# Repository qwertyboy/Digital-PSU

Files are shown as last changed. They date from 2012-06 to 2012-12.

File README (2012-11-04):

Digital PSU

This originally started life as the revision B EEVBlog power supply project, but I have made several changes to my version of the design. The first revision of ym design was pretty much a carbon copy of the EEVBlog design, but removed the USB jack and the micro current section. The board was designed with all through-hole components, except for the components that only come in SMD packages, and as a result, was larger and more expensive to produce. The new version, however, only uses through-hole versions of the DAC, ADC, op-amps, the LT3080, and a couple filter capacitors. Instead of using an atmega328 now, it uses an Xmega A4, both for speed and for I/O count. Also changed are the elimination of the push-buttons and MCP23008 I/O expanders.

Key Features:
	-Xmega A4 simplifies design by eliminating need for I/O expansion
	-LT3080 as main output regulator
	-MCP4922 digital-to-analog converter
	-MCP3204 analog-to-digital converter
	-MAX4080F for current sensing
	-Easily readible OLED display
	-Intuitive menu system for set-up and calibration

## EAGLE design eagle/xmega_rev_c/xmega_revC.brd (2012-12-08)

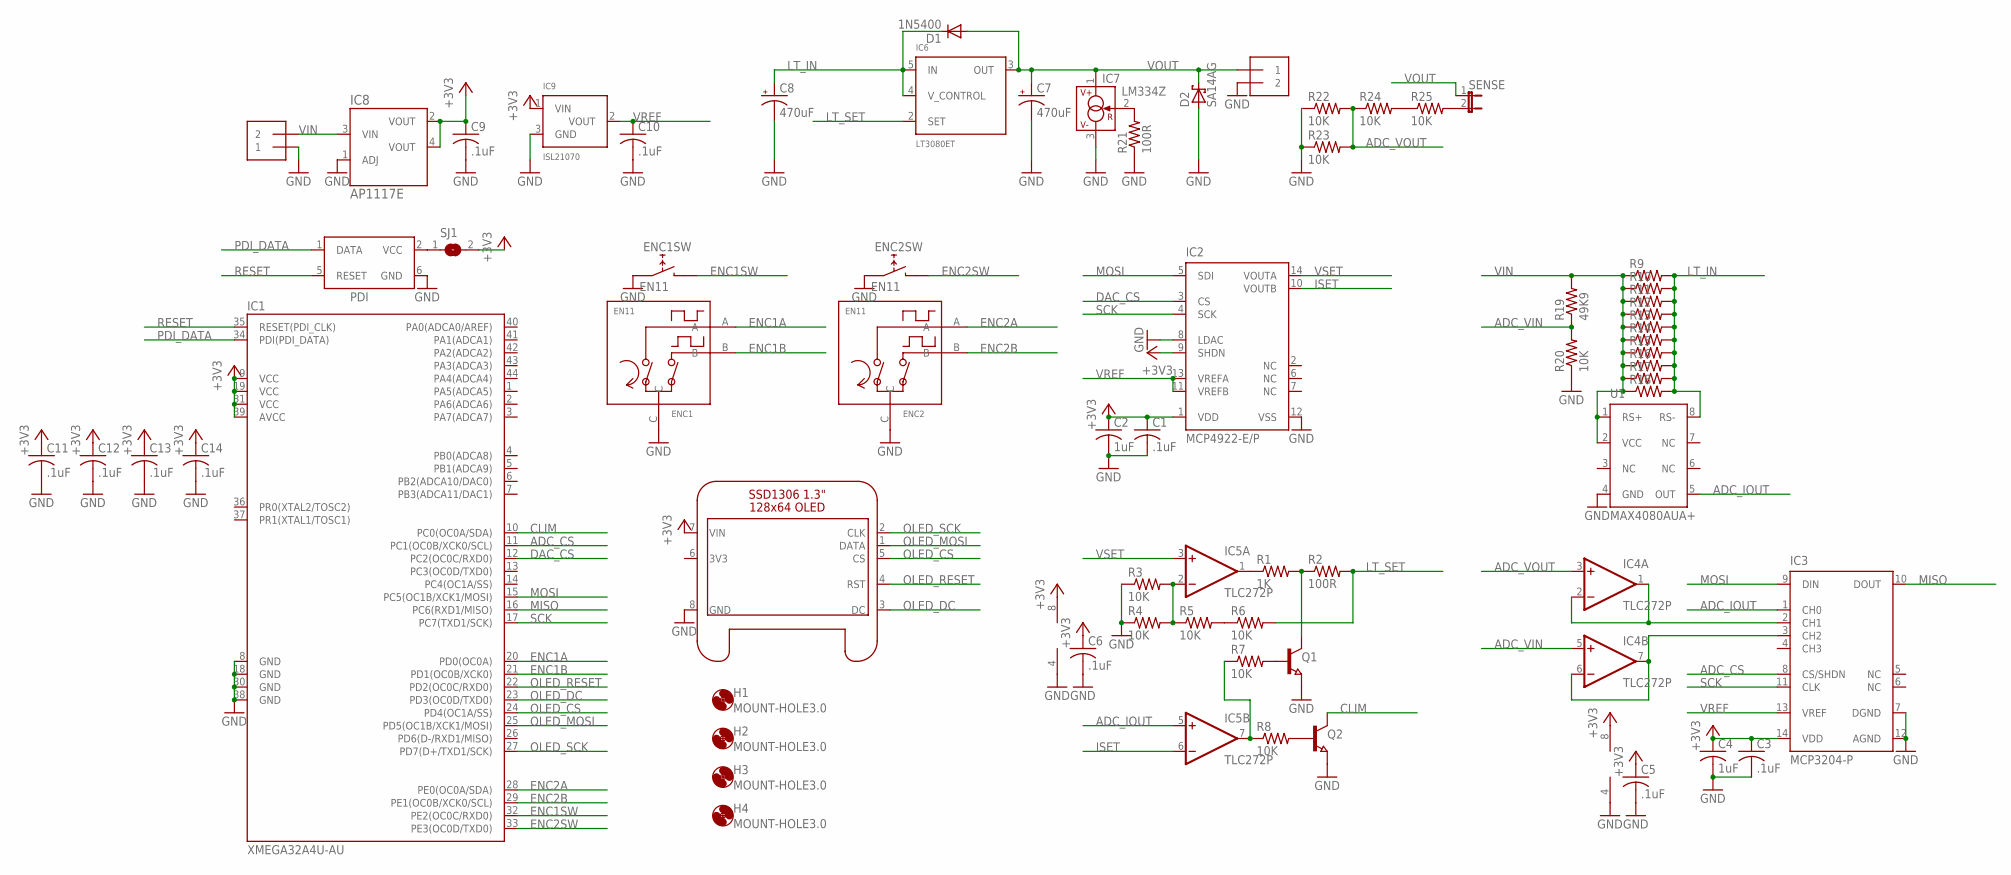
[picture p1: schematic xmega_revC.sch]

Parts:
C1, C3, C5, C6, C9, C10: .1uF; C050-024X044
C2, C4: 1uF; C050-024X044
C7, C8: 470uF; E5-10,5
C11, C12, C13, C14: .1uF; C0805K
D1: 1N5400; DO201-15
D2: SA14AG; DO41-7
ENC1, ENC2: EN11; EN11-VS*
H1, H2, H3, H4: MOUNT-HOLE3.0; 3,0
IC1: XMEGA32A4U-AU; TQFP44
IC2: MCP4922-E/P; DIL14
IC3: MCP3204-P; DIL14
IC4, IC5: TLC272P; DIL08
IC6: LT3080ET; TO220-51
IC7: LM334Z; TO92
IC8: AP1117E; SOT223-3
IC9: ISL21070; SOT-23
OLED1: 128X64_OLED
OUT: 1X2-3.5MM
PDI: XMEGAPDI; AVRISP
Q1, Q2: NPN-TRANSISTOR_SOT23; SOT23
R1: 1K; R0805
R2, R21: 100R; R0805
R3, R4, R5, R6, R7, R8, R20, R22, R23, R24, R25: 10K; R0805
R9, R10, R11, R12, R13, R14, R15, R16, R17, R18: R-US_0207/10; 0207/10
R19: 49K9; R0805
SENSE: JP1E; JP1
SJ1: SJ
U1: MAX4080AUA+; SO08
VIN: 1X2-3.5MM

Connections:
3V3: OLED1.6 (3V3)
+3V3: C1.1, C2.1, C3.1, C4.1, C5.1, C6.1, C9.1, C11.1, C12.1, C13.1, C14.1, IC1.9 (VCC), IC1.19 (VCC), IC1.31 (VCC), IC1.39 (AVCC), IC2.1 (VDD), IC2.9 (SHDN), IC3.14 (VDD), IC4.8 (V+), IC5.8 (V+), IC8.2 (VOUT), IC8.4 (VOUT), IC9.1 (VIN), OLED1.7 (VIN), SJ1.2
ADC_CS: IC1.11 (PC1(OC0B/XCK0/SCL)), IC3.8 (CS/SHDN)
ADC_IOUT: IC3.1 (CH0), IC5.5 (+IN), U1.5 (OUT)
ADC_VIN: IC4.5 (+IN), R19.1, R20.2
ADC_VOUT: IC4.3 (+IN), R22.2, R23.2, R24.1
CLIM: IC1.10 (PC0(OC0A/SDA)), Q2.3 (C)
DAC_CS: IC1.12 (PC2(OC0C/RXD0)), IC2.3 (CS)
ENC1A: ENC1.A, IC1.20 (PD0(OC0A))
ENC1B: ENC1.B, IC1.21 (PD1(OC0B/XCK0))
ENC1SW: ENC1.E, IC1.32 (PE2(OC0C/RXD0))
ENC2A: ENC2.A, IC1.28 (PE0(OC0A/SDA))
ENC2B: ENC2.B, IC1.29 (PE1(OC0B/XCK0/SCL))
ENC2SW: ENC2.E, IC1.33 (PE3(OC0D/TXD0))
GND: C1.2, C2.2, C3.2, C4.2, C5.2, C6.2, C7.-, C8.-, C9.2, C10.2, C11.2, C12.2, C13.2, C14.2, D2.A, ENC1.C, ENC1.D, ENC2.C, ENC2.D, IC1.8 (GND), IC1.18 (GND), IC1.30 (GND), IC1.38 (GND), IC2.8 (LDAC), IC2.12 (VSS), IC3.7 (DGND), IC3.12 (AGND), IC4.4 (V-), IC5.4 (V-), IC7.3 (V-), IC8.1 (ADJ), IC9.3 (GND), OLED1.8 (GND), OUT.2, PDI.6 (GND), Q1.2 (E), Q2.2 (E), R3.1, R4.1, R20.1, R21.1, R22.1, R23.1, U1.4 (GND), VIN.1
ISET: IC2.10 (VOUTB), IC5.6 (-IN)
LT_IN: C8.+, D1.C, IC6.4 (V_CONTROL), IC6.5 (IN), R9.2, R10.2, R11.2, R12.2, R13.2, R14.2, R15.2, R16.2, R17.2, R18.2, U1.8 (RS-)
LT_SET: IC6.2 (SET), R2.2, R6.2
MISO: IC1.16 (PC6(RXD1/MISO)), IC3.10 (DOUT)
MOSI: IC1.15 (PC5(OC1B/XCK1/MOSI)), IC2.5 (SDI), IC3.9 (DIN)
unnamed: IC3.2 (CH1), IC4.1 (OUT), IC4.2 (-IN)
unnamed: IC3.3 (CH2), IC4.6 (-IN), IC4.7 (OUT)
unnamed: IC5.1 (OUT), R1.1
unnamed: Q1.3 (C), R1.2, R2.1
unnamed: IC5.2 (-IN), R3.2, R4.2, R5.1
unnamed: R5.2, R6.1
unnamed: Q1.1 (B), R7.2
unnamed: IC5.7 (OUT), R7.1, R8.1
unnamed: Q2.1 (B), R8.2
unnamed: R25.2, SENSE.2
unnamed: PDI.2 (VCC), SJ1.1
unnamed: IC7.2 (R), R21.2
unnamed: R24.2, R25.1
OLED_CS: IC1.24 (PD4(OC1A/SS)), OLED1.5 (CS)
OLED_DC: IC1.23 (PD3(OC0D/TXD0)), OLED1.3 (DC)
OLED_MOSI: IC1.25 (PD5(OC1B/XCK1/MOSI)), OLED1.1 (DATA)
OLED_RESET: IC1.22 (PD2(OC0C/RXD0)), OLED1.4 (RST)
OLED_SCK: IC1.27 (PD7(D+/TXD1/SCK)), OLED1.2 (CLK)
PDI_DATA: IC1.34 (PDI(PDI_DATA)), PDI.1 (DATA)
RESET: IC1.35 (RESET(PDI_CLK)), PDI.5 (RESET)
SCK: IC1.17 (PC7(TXD1/SCK)), IC2.4 (SCK), IC3.11 (CLK)
VIN: IC8.3 (VIN), R9.1, R10.1, R11.1, R12.1, R13.1, R14.1, R15.1, R16.1, R17.1, R18.1, R19.2, U1.1 (RS+), U1.2 (VCC), VIN.2
VOUT: C7.+, D1.A, D2.C, IC6.3 (OUT), IC7.1 (V+), OUT.1, SENSE.1
VREF: C10.1, IC2.11 (VREFB), IC2.13 (VREFA), IC3.13 (VREF), IC9.2 (VOUT)
VSET: IC2.14 (VOUTA), IC5.3 (+IN)

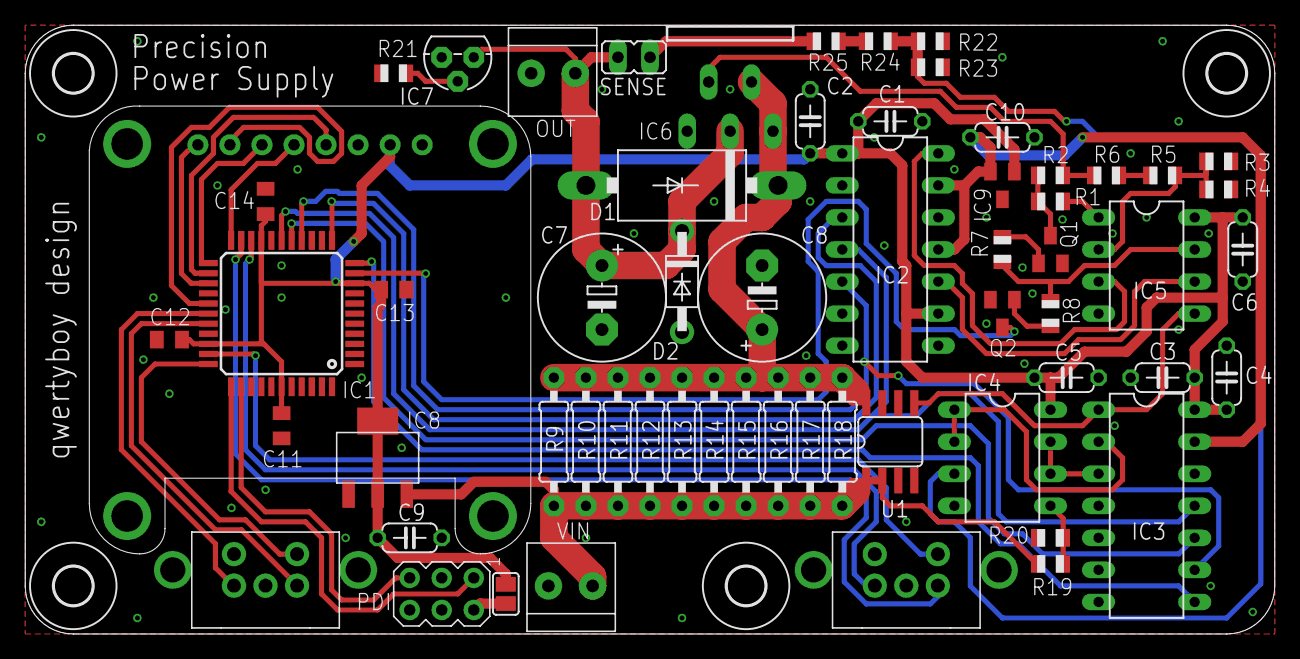
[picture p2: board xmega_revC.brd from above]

Board: 2 copper layers, 99.1 x 48.3 mm, 65 parts (0 on the bottom side), 44 nets.

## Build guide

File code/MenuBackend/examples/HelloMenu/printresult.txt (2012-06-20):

Setting up menu...
Starting navigation (see source for description):
Menu change MenuRoot File
Menu change File New
Menu change New Open
Menu change Open Examples
Menu change Examples ArduinoISP
Menu use ArduinoISP
menuUseEvent found ArduinoISP
Menu change ArduinoISP Examples
Menu change Examples Open
Menu change Open New
Menu change New File
Menu change File Edit
Menu change Edit Sketch
Menu change Sketch Verify
Menu use Verify
Menu change Verify Sketch
Menu change Sketch Edit
Menu change Edit File
Menu change File New
Menu use New
Menu use Verify
menuUseEvent found Verify (V)

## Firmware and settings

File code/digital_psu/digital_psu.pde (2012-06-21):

//Board should be set to "Arduino Pro or Pro Mini (3.3V, 8MHz) w/ ATmega328"
#include <WProgram.h>
#include <Wire.h>
#include "ST7036.h"
#include "LCD_C0220BiZ.h"
#include "MCP23008.h"
#include <MenuBackend.h>

//-----------------------------------------------------------------------------------------------------------------------------------------------------------------//
//Variable nad constant initialization, initialiazation of MCP23008 library, ST7036 librar

//Start 2 instances of MCP23008 library
MCP23008 mcp_internal;  //This one is for controlling various peripherals
MCP23008 mcp_general;  //This one is for general purpose use. The LCD backlight is also on here

//Start instance of I2C LCD library
ST7036 lcd = ST7036(2, 20, 0x78);

//Define some constants
//The first four here are on mcp_internal
#define DAC_CS 1
#define ADC_CS 0
#define RANGE 2  //Range selection for rev.B boards, not used anyway
#define LCD_RESET 3

//These are on mcp_general
#define BACKLIGHT_PIN 7
byte buttons[] = {0, 0, 0, 0};  //Array to store states of onboard buttons
#define MENUBUTTON 0

//Rotary encoder pins
#define ENC1A 2
#define ENC1B 4
#define ENC2A 3
#define ENC2B 7

//These are the counts for the rotary encoders. They are volatile because they will be modified
//in an interrupt and we don't want the compiler to try and optimise these
volatile unsigned int VOLTAGE_POS = 0;
volatile unsigned int CURRENT_POS = 0;

//ADC stuff
int adcVals[] = {0, 0, 0, 0};  //Array to store the different ADC values
//Define some ADC constants
#define IOUT200 0
#define IOUT 1
#define VOUT 2
#define VIN 3
float VOLTAGE_PRINT_DIVISOR = 333.889816;  //This is to output the correct value after voltage
                                           //divider and ADC. Only to be used for VIN

//These are for SPI communication and are located directly on the AVR
#define SPI_DATA A0
#define SPI_CLK A3
#define ADC_DATA A1
#define SPI_CLK_CTRL digitalWrite(SPI_CLK, HIGH); digitalWrite(SPI_CLK, LOW);  //Macro to 'clock' the clock

//-----------------------------------------------------------------------------------------------------------------------------------------------------------------//

//MULTI-CLICK: One Button, Multiple Events

//Timing variables
byte DEBOUNCE = 20;
byte DOUBLE_CLICK_GAP = 250;
byte HOLDTIME = 2000;
byte LONG_HOLDTIME = 5000;

//Other variables
boolean BUTTONVAL = HIGH;
boolean BUTTONLAST = HIGH;
boolean DOUBLE_CLICK_WAITING = false;
boolean DOUBLE_CLICK_UP = false;
boolean SINGLE_OK = true;
long DOWNTIME = -1;
long UPTIME = -1;
boolean IGNOREUP = false;
boolean UP_WAIT = false;
boolean HOLD_EVENT_PAST = false;
boolean LONG_HOLD_EVENT_PAST = false;

//Call to check button
int menuButton()
{
  int event = 0;
  
  //Read button state - first one on mcp_general
  BUTTONVAL = mcp_general.digitalRead(MENUBUTTON);
  
  //Button pressed
  if(BUTTONVAL == LOW && BUTTONLAST == HIGH && (millis() - UPTIME) > DEBOUNCE){
    DOWNTIME = millis();
    IGNOREUP = false;
    UP_WAIT = false;
    SINGLE_OK = true;
    HOLD_EVENT_PAST = false;
    LONG_HOLD_EVENT_PAST = false;
    
    if((millis() - UPTIME) < DOUBLE_CLICK_GAP && DOUBLE_CLICK_UP == false && DOUBLE_CLICK_WAITING == true) DOUBLE_CLICK_UP = true;
    else DOUBLE_CLICK_UP = false;
    DOUBLE_CLICK_WAITING = false;
  }
  
  //Button released
  else if(BUTTONVAL == HIGH && BUTTONLAST == LOW && (millis() - DOWNTIME) > DEBOUNCE){
    if(!IGNOREUP){
      UPTIME = millis();
      if(DOUBLE_CLICK_UP == false) DOUBLE_CLICK_WAITING = true;
      else{
        event = 2;
        DOUBLE_CLICK_UP = false;
        DOUBLE_CLICK_WAITING = false;
        SINGLE_OK = false;
      }
    }
  }
  
  //Normal click event; double click expired
  if(BUTTONVAL == HIGH && (millis() - UPTIME) >= DOUBLE_CLICK_GAP && DOUBLE_CLICK_WAITING == true && DOUBLE_CLICK_UP == false && SINGLE_OK == true){
    event = 1;
    DOUBLE_CLICK_WAITING = false;
  }
  
  //Test for hold
  if(BUTTONVAL == LOW && (millis() - DOWNTIME) >= HOLDTIME){
    //Trigger short hold
    if(!HOLD_EVENT_PAST){
      event = 3;
      UP_WAIT = true;
      IGNORE_UP = true;
      DOUBLE_CLICK_UP = false;
      DOUBLE_CLICK_WAITING = false;
      HOLD_EVENT_PAST = true;
    }
    
    //Trigger long hold
    if((millis() - DOWNTIME) >= LONG_HOLDTIME){
      if(!LONG_HOLD_EVENT_PAST){
        event = 4;
        LONG_HOLD_EVENT_PAST = true;
      }
    }
  }
  BUTTONLAST = BUTTONVAL;
  return event;
}
    
     
//-----------------------------------------------------------------------------------------------------------------------------------------------------------------//

//Menu system! This area contains stuff for setting up and using the menu
/*
root
  Presets      Settings
    1.8V         Calibration
    2.5V           Auto
    3.3V           Manual
    5.0V         LCD
                   Backlight
                   Contrast
*/
//Start instance fo Menu Backend library
MenuBackend menu = MenuBackend(menuUseEvent, menuChangeEvent);

//Preset voltage menu
MenuItem mPresets = MenuItem("Presets");
  MenuItem m1v8 = MenuItem("1.8V");
  MenuItem m2v5 = MenuItem("2.5V");
  MenuItem m3v3 = MenuItem("3.3V");
  MenuItem m5v = MenuItem("5.0V");
  
//Settings menu
MenuItem mSettings = MenuItem("Settings");
  MenuItem mCalibration = MenuItem("Calibration");
    MenuItem mAuto = MenuItem("Auto");
    MenuItem mManual = MenuItem("Manual");
  MenuItem mLCD = MenuItem("LCD");
    MenuItem mBacklight = MenuItem("Backlight");
    MenuItem mContrast = MenuItem("Contrast");
    
void menuSetup()
{
  menu.getRoot().add(mPresets).add(mSettings);           //Add Presets and Settings to root
  mPresets.addRight(m1v8).add(m2v5).add(m3v3).add(m5v);  //Add options under Presets
  mSettings.add(mCalibration).add(mLCD);                 //Add options under Settings
  mCalibration.addRight(mAuto).add(mManual);             //Add options under Calibration
  mLCD.addRight(mBacklight).add(mContrast);              //Add options under LCD
}

void menuUseEvent(MenuUseEvent used)
{
}

//Currently prints what happened to the serial port
void menuChangeEvent(MenuChangeEvent changed)
{
  Serial.print("Menu change ");
  Serial.print(changed.from.getName());
  Serial.print(" ");
  Serial.println(changed.to.getName());
}

//VERY rough way to read buttons, doesn't really work
void menuNav()
{
  if(buttons[0] == 0){
    menu.moveDown();
    delay(10);
  }
  
  if(buttons[1] == 0){
    menu.moveUp();
    delay(10);
  }
  
  if(buttons[2] == 0){
    menu.moveLeft();
    delay(10);
  }
  
  if(buttons[3] == 0){
    menu.moveRight();
    delay(10);
  }
}

//-----------------------------------------------------------------------------------------------------------------------------------------------------------------//

void setup()
{
  Serial.begin(9600);  //Serial for debugging
  
  //Start the library for the two MCP23008's
  mcp_internal.begin(0);
  mcp_general.begin(8);

  //Bring LCD_RESET high to enable LCD
  mcp_internal.pinMode(LCD_RESET, OUTPUT);
  mcp_internal.digitalWrite(LCD_RESET, HIGH);

  //Bring CS lines high to ignore stray data
  mcp_internal.pinMode(DAC_CS, OUTPUT);
  mcp_internal.pinMode(ADC_CS, OUTPUT);
  mcp_internal.digitalWrite(DAC_CS, HIGH);
  mcp_internal.digitalWrite(ADC_CS, HIGH);

  //Set SPI pins as outputs
  pinMode(SPI_DATA, OUTPUT);
  pinMode(SPI_CLK, OUTPUT);
  pinMode(ADC_DATA, INPUT);

  //Set up rotary encoder pins
  pinMode(ENC1A, INPUT);
  pinMode(ENC1B, INPUT);
  pinMode(ENC2A, INPUT);
  pinMode(ENC2B, INPUT);
  digitalWrite(ENC1A, HIGH);
  digitalWrite(ENC1B, HIGH);
  digitalWrite(ENC2A, HIGH);
  digitalWrite(ENC2B, HIGH);
  
  //Set up button inputs on mcp_general
  mcp_general.pinMode(0, INPUT);
  mcp_general.pinMode(1, INPUT);
  mcp_general.pinMode(2, INPUT);
  mcp_general.pinMode(3, INPUT);

  //Set up interrupts for rotary encoders
  attachInterrupt(0, voltageChange, CHANGE);
  attachInterrupt(1, currentChange, CHANGE);
  
  menuSetup();

  //Initialize the LCD
  lcd.init();
  lcd.setContrast(10);
  //Turn on backlight. Power pin is connected to mcp_general GP7
  mcp_general.pinMode(BACKLIGHT_PIN, OUTPUT);
  mcp_general.digitalWrite(BACKLIGHT_PIN, HIGH);
  lcd.clear();

  //Start up niceness  
  lcd.setCursor(0, 6);
  lcd.print("uSupply");
  lcd.setCursor(1, 1);
  lcd.print("Bench Power Supply");
  delay(2000);
  lcd.clear();
}

void loop()
{
  //int vVal = map(VOLTAGE_POS, 0, 1024, 0, 2048);
  //dacSend(1, vVal);

  //int cVal = map(CURRENT_POS, 0, 1024, 0, 2048);
  //dacSend(2, cVal);

  //adcRead(IOUT);
  //adcRead(VOUT);
  //adcRead(VIN);

  //updateDisplay();
  readButtons();
  //for(byte b = 0; b < 4; b++){
  //  Serial.println(buttons[b], DEC);
  //}
  
  menuNav();
}

//-----------------------------------------------------------------------------------------------------------------------------------------------------------------//

//This gets called when the voltage set encoder is changed
void voltageChange()
{
  if(digitalRead(ENC1A) != digitalRead(ENC1B)){
    VOLTAGE_POS++;
  }else{
    VOLTAGE_POS--;
  }

  if(VOLTAGE_POS >= 1024){
    VOLTAGE_POS = 1024;
  }

  if(VOLTAGE_POS <= 0){
    VOLTAGE_POS = 0;
  }
  delay(20);
}

//-----------------------------------------------------------------------------------------------------------------------------------------------------------------//

//This gets called when the current set encoder is changed
void currentChange()
{
  if(digitalRead(ENC2A) != digitalRead(ENC2B)){
    CURRENT_POS++;
  }else{
    CURRENT_POS--;
  }

  if(CURRENT_POS >= 1024){
    CURRENT_POS = 1024;
  }

  if(CURRENT_POS <= 0){
    CURRENT_POS = 0;
  }
}

//-----------------------------------------------------------------------------------------------------------------------------------------------------------------//

//Set "channel" as 1 for voltage, 2 for current. Maximum "value" is 1023, because we are using 10 bits. Maximum is 4095 if using all 12 bits
//Bit-bang the DAC
void dacSend(byte channel, int value)
{
  unsigned int temp;

  //Bring CS low to enable communication
  mcp_internal.digitalWrite(DAC_CS, LOW);

  //If "channel" is set to volatge, send a LOW bit, vice-versa for current
  if(channel == 1){
    digitalWrite(SPI_DATA, LOW);
  }else{
    digitalWrite(SPI_DATA, HIGH);
  }

  SPI_CLK_CTRL
    digitalWrite(SPI_DATA, LOW);  //Unbuffered VREF input
  SPI_CLK_CTRL
    digitalWrite(SPI_DATA, LOW);  //Output gain x2
  SPI_CLK_CTRL
    digitalWrite(SPI_DATA, HIGH);  //Disable shutdown
  SPI_CLK_CTRL
    temp = value;
  digitalWrite(SPI_DATA, ((temp>>11) & 1));  //Only using 10 bits of 12 bit DAC. It won't work without these
  SPI_CLK_CTRL
    temp = value;
  digitalWrite(SPI_DATA, ((temp>>10) & 1));
  SPI_CLK_CTRL
    temp = value;
  digitalWrite(SPI_DATA, ((temp>>9) & 1));
  SPI_CLK_CTRL
    temp = value;
  digitalWrite(SPI_DATA, ((temp>>8) & 1));
  SPI_CLK_CTRL
    temp = value;
  digitalWrite(SPI_DATA, ((temp>>7) & 1));
  SPI_CLK_CTRL
    temp = value;
  digitalWrite(SPI_DATA, ((temp>>6) & 1));
  SPI_CLK_CTRL
    temp = value;
  digitalWrite(SPI_DATA, ((temp>>5) & 1));
  SPI_CLK_CTRL
    temp = value;
  digitalWrite(SPI_DATA, ((temp>>4) & 1));
  SPI_CLK_CTRL
    temp = value;
  digitalWrite(SPI_DATA, ((temp>>3) & 1));
  SPI_CLK_CTRL
    temp = value;
  digitalWrite(SPI_DATA, ((temp>>2) & 1));
  SPI_CLK_CTRL
    temp = value;
  digitalWrite(SPI_DATA, ((temp>>1) & 1));
  SPI_CLK_CTRL
    temp = value;
  digitalWrite(SPI_DATA, temp & 1);
  SPI_CLK_CTRL

  //Done sending data, so set the CS pin high to "latch" the data
  mcp_internal.digitalWrite(DAC_CS, HIGH);
}

//-----------------------------------------------------------------------------------------------------------------------------------------------------------------//

//We read from the ADC over SPI using this function to bit-bang
void adcRead(byte ADC_CHANNEL)
{
  byte i;  //Variable for storing the read bit from the ADC


  mcp_internal.digitalWrite(ADC_CS, LOW);  //Set ADC CS line low to begin comms

  digitalWrite(SPI_DATA, HIGH);  //Start bit
  SPI_CLK_CTRL
  digitalWrite(SPI_DATA, HIGH);  //Single input mode
  SPI_CLK_CTRL
  digitalWrite(SPI_DATA, LOW);  //D2 setup bit - this gets ignored when in single input mode
  SPI_CLK_CTRL

  if(ADC_CHANNEL == 0){  //Send set up for channel 0
    digitalWrite(SPI_DATA, LOW);
    SPI_CLK_CTRL
    digitalWrite(SPI_DATA, LOW);
    SPI_CLK_CTRL
  }

  if(ADC_CHANNEL == 1){  //Send set up for channel 1
    digitalWrite(SPI_DATA, LOW);
    SPI_CLK_CTRL
    digitalWrite(SPI_DATA, HIGH);
    SPI_CLK_CTRL
  }
  
  if(ADC_CHANNEL == 2){  //Send set up for channel 2
    digitalWrite(SPI_DATA, HIGH);
    SPI_CLK_CTRL
    digitalWrite(SPI_DATA, LOW);
    SPI_CLK_CTRL
  }
  
  if(ADC_CHANNEL == 3){  //Send set up for channel 3
    digitalWrite(SPI_DATA, HIGH);
    SPI_CLK_CTRL
    digitalWrite(SPI_DATA, HIGH);
    SPI_CLK_CTRL
  }

  //We are done sending setup data. Now we need to listen for data, MSB first, 12 bits

  //The first recieved bit is null, ignore it
  SPI_CLK_CTRL

    i = digitalRead(ADC_DATA);  //bit 11
  bitWrite(adcVals[ADC_CHANNEL], 11, i);  //Write the first bit received to the correct array element
  SPI_CLK_CTRL

    i = digitalRead(ADC_DATA);  //bit 10
  bitWrite(adcVals[ADC_CHANNEL], 10, i);
  SPI_CLK_CTRL

    i = digitalRead(ADC_DATA);  //bit 9
  bitWrite(adcVals[ADC_CHANNEL], 9, i);
  SPI_CLK_CTRL

    i = digitalRead(ADC_DATA);  //bit 8
  bitWrite(adcVals[ADC_CHANNEL], 8, i);
  SPI_CLK_CTRL

    i = digitalRead(ADC_DATA);  //bit 7
  bitWrite(adcVals[ADC_CHANNEL], 7, i);
  SPI_CLK_CTRL

    i = digitalRead(ADC_DATA);  //bit 6
  bitWrite(adcVals[ADC_CHANNEL], 6, i);
  SPI_CLK_CTRL

    i = digitalRead(ADC_DATA);  //bit 5
  bitWrite(adcVals[ADC_CHANNEL], 5, i);
  SPI_CLK_CTRL

    i = digitalRead(ADC_DATA);  //bit 4
  bitWrite(adcVals[ADC_CHANNEL], 4, i);
  SPI_CLK_CTRL

    i = digitalRead(ADC_DATA);  //bit 3
  bitWrite(adcVals[ADC_CHANNEL], 3, i);
  SPI_CLK_CTRL

    i = digitalRead(ADC_DATA);  //bit 2
  bitWrite(adcVals[ADC_CHANNEL], 2, i);
  SPI_CLK_CTRL

    i = digitalRead(ADC_DATA);  //bit 1
  bitWrite(adcVals[ADC_CHANNEL], 1, i);
  SPI_CLK_CTRL

    i = digitalRead(ADC_DATA);  //bit 0
  bitWrite(adcVals[ADC_CHANNEL], 0, i);
  SPI_CLK_CTRL

  mcp_internal.digitalWrite(ADC_CS, HIGH);
}

//-----------------------------------------------------------------------------------------------------------------------------------------------------------------//

void updateDisplay()
{
  lcd.setCursor(0, 0);
  lcd.print("SET: ");
  lcd.print(VOLTAGE_POS / 100.00);
  lcd.print("V ");
  lcd.setCursor(0, 12);
  lcd.print(CURRENT_POS);
  lcd.print("mA  ");

  lcd.setCursor(1, 0);
  lcd.print("OUT: ");
  lcd.print(adcVals[IOUT]);
  lcd.print(",");
  lcd.print(adcVals[VOUT]);
  lcd.print(",");
  lcd.print((adcVals[VIN] * 2) / VOLTAGE_PRINT_DIVISOR);  //We calculate the actual voltage AFTER the voltage divider, and ADC
  lcd.print("    ");
}

//-----------------------------------------------------------------------------------------------------------------------------------------------------------------//

void readButtons()
{
  for(byte buttonNumber = 0; buttonNumber < 4; buttonNumber++){
    byte buttonState = mcp_general.digitalRead(buttonNumber);
    buttons[buttonNumber] = buttonState;
  }
}

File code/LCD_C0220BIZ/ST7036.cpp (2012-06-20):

// ---------------------------------------------------------------------------
// Created by Francisco Malpartida on 20/08/11.
// Copyright 2011 - Under creative commons license 3.0:
//        Attribution-ShareAlike CC BY-SA
//
// This software is furnished "as is", without technical support, and with no 
// warranty, express or implied, as to its usefulness for any purpose.
//
// Thread Safe: No
// Extendable: No
//
// @file LCD_C0220BiZ.cpp
// Display class implementation of the LCD API 1.0
// 
// @brief Based on the LCD API 1.0 by dale@wentztech.com
//        This library implements the driver to any I2C display with the ST7036
//        LCD controller. 
//        I2C displays based on the ST7032i should also be compatible.
//
//        Other compatible displays:
//           - NHD‐C0220BiZ‐FSW‐FBW‐3V3M
//           - NHD-C0220BiZ-FS(RGB)-FBW-3VM
//        Non tested but should be compatible with no or little changes
//           - NHD-C0216CiZ-FSW-FBW-3V3
//           - NHD‐C0216CiZ‐FN‐FBW‐3V
//
//
// @author F. Malpartida - fmalpartida@gmail.com
// ---------------------------------------------------------------------------
#include <WProgram.h>
#include <WConstants.h>		//all things wiring / arduino
#include <Wire.h>
#include <string.h>			//needed for strlen()
#include <inttypes.h>

#include "LCD.h"
#include "ST7036.h"

// Class private constants and definition 
// ----------------------------------------------------------------------------
const int     CMD_DELAY           = 1;  // Command delay in miliseconds
const int     CHAR_DELAY          = 0;  // Delay between characters in miliseconds
const int     PIXEL_ROWS_PER_CHAR = 8;  // Number of pixel rows in the LCD character
const int     MAX_USER_CHARS      = 16; // Maximun number of user defined characters

// LCD Command set
const uint8_t DISP_CMD       = 0x0;  // Command for the display
const uint8_t RAM_WRITE_CMD  = 0x40; // Write to display RAM
const uint8_t CLEAR_DISP_CMD = 0x01; // Clear display command
const uint8_t HOME_CMD       = 0x02; // Set cursos at home (0,0)
const uint8_t DISP_ON_CMD    = 0x0C; // Display on command
const uint8_t DISP_OFF_CMD   = 0x08; // Display off Command
const uint8_t SET_DDRAM_CMD  = 0x80; // Set DDRAM address command
const uint8_t CONTRAST_CMD   = 0x70; // Set contrast LCD command
const uint8_t FUNC_SET_TBL0  = 0x38; // Function set - 8 bit, 2 line display 5x8, inst table 0
const uint8_t FUNC_SET_TBL1  = 0x39; // Function set - 8 bit, 2 line display 5x8, inst table 1

// LCD bitmap definition
const uint8_t CURSOR_ON_BIT  = ( 1 << 1 );// Cursor selection bit in Display on cmd.
const uint8_t BLINK_ON_BIT   = ( 1 << 0 );// Blink selection bit on Display on cmd. 

// Driver DDRAM addressing
const uint8_t dram_dispAddr [][3] =
{
   { 0x00, 0x00, 0x00 },  // One line display address
   { 0x00, 0x40, 0x00 },  // Two line display address
   { 0x00, 0x10, 0x20 }   // Three line display address
};

// Static  member variable definitions
// ----------------------------------------------------------------------------

// Static file scope variable definitions
// ----------------------------------------------------------------------------

// Private support functions
// ----------------------------------------------------------------------------

// CLASS METHODS
// ----------------------------------------------------------------------------

// Constructors:
// ---------------------------------------------------------------------------
ST7036::ST7036(uint8_t num_lines, uint8_t num_col, 
               uint8_t i2cAddr )
{
   _num_lines    = num_lines;
	_num_col      = num_col;
   _i2cAddress   = ( i2cAddr >> 1 );
   _cmdDelay     = CMD_DELAY;
   _charDelay    = CHAR_DELAY;
   _initialised  = false;
   _backlightPin = -1;
   
}

ST7036::ST7036(uint8_t num_lines, uint8_t num_col, 
               uint8_t i2cAddr, int8_t backlightPin )
{
   _num_lines    = num_lines;
	_num_col      = num_col;
   _i2cAddress   = ( i2cAddr >> 1 );
   _cmdDelay     = CMD_DELAY;
   _charDelay    = CHAR_DELAY;
   _initialised  = false;
   _backlightPin = backlightPin;
   
   // If there is a pin assigned to the BL, set it as an output
   // ---------------------------------------------------------
   if ( _backlightPin != 0 )
   {
      pinMode ( _backlightPin, OUTPUT );
   }
   
}

// Functions: modifiers (set), selectors (get) and class methods
// ---------------------------------------------------------------------------
void ST7036::init () 
{
   
   // Initialise the Wire library.
   Wire.begin();
   
   Wire.beginTransmission ( _i2cAddress );
   Wire.send ( 0x0 );   // Send command to the display
   Wire.send ( FUNC_SET_TBL0 );
   delay (10);
   Wire.send ( FUNC_SET_TBL1 );
   delay (10);
   Wire.send ( 0x14 );  // Set BIAS - 1/5
   Wire.send ( 0x73 );  // Set contrast low byte
   Wire.send ( 0x5E );  // ICON disp on, Booster on, Contrast high byte 
   Wire.send ( 0x6D );  // Follower circuit (internal), amp ratio (6)
   Wire.send ( 0x0C );  // Display on
   Wire.send ( 0x01 );  // Clear display
   Wire.send ( 0x06 );  // Entry mode set - increment
   _status = Wire.endTransmission ();
   
   if ( _status == 0 )
   {
      _initialised = true;
   }
}


void ST7036::setDelay (int cmdDelay,int charDelay) 
{
	_cmdDelay = cmdDelay;
	_charDelay = charDelay;
}


void ST7036::command(uint8_t value) 
{
   // If the LCD has been initialised correctly, write to it
   if ( _initialised )
   {
      Wire.beginTransmission ( _i2cAddress );
      Wire.send ( DISP_CMD );
      Wire.send ( value );
      _status = Wire.endTransmission ();
      delay(_cmdDelay);
   }
}


void ST7036::write(uint8_t value) 
{
   // If the LCD has been initialised correctly write to it
   // -----------------------------------------------------
   if ( _initialised )
   {
      
      // If it is a new line, set the cursor to the next line (1,0)
      // ----------------------------------------------------------
      if ( value == '\n' )
      {
         setCursor (1,0);
      }
      else
      {
         Wire.beginTransmission ( _i2cAddress );
         Wire.send ( RAM_WRITE_CMD );
         Wire.send ( value );
         _status = Wire.endTransmission ();
         delay(_charDelay);
      }
   }
}

void ST7036::write(const uint8_t *buffer, size_t size)
{
   // If the LCD has been initialised correctly, write to it
   // ------------------------------------------------------
   if ( _initialised )
   {
      Wire.beginTransmission ( _i2cAddress );
      Wire.send ( RAM_WRITE_CMD );
      Wire.send ( (uint8_t *)buffer, size );
      _status = Wire.endTransmission ();
      delay(_charDelay);
   }
}


void ST7036::clear()
{
   command (CLEAR_DISP_CMD);
}


void ST7036::home()
{
   command ( HOME_CMD );
}


void ST7036::on()
{   
   command ( DISP_ON_CMD );
}


void ST7036::off()
{
   command ( DISP_OFF_CMD );        
}


void ST7036::cursor_on()
{
   command ( DISP_ON_CMD | CURSOR_ON_BIT );
}
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

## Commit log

2012-05-11 First commit. Added EAGLE schematic and layout files
    [revC.brd, revC.sch]
2012-05-11 Added Arduino code. For Arduino version < 1
2012-05-13 Now displaying voltage output
2012-06-20 Got menu set up correctly. Added _very_ touchy button navigation.
    [digital_psu.pde]
2012-06-20 Renamed some constants and variables; hopefully didn't break anything
    [digital_psu.pde]
2012-06-21 BACKUP. I added a function to detect 4 different states on one button.
2012-12-08 Added schematic and board for the newest revision, code is in progress
    [revB.brd, revB.sch, revC.brd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]
2012-12-08 Removed renamed files
    [revC.brd, revC.sch]
2012-12-08 Fixing folder names. I need to get better at this ;)
    [revB.brd, revB.sch]
